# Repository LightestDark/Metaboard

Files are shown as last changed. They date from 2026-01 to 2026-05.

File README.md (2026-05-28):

# Metaboard
I made a small development board that uses a microcontroller to control an LED, letting it turn on, off, or blink based on the code running on it. It’s a simple platform for testing firmware, GPIO control, and basic hardware–software interaction.

# Production









# CASE




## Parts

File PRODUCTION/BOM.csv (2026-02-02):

JLCPCB BOM Tool - BOM Matching
BOM name?Metaboard-JLCPCB Assembly Order.xlsx |  |  |  | Download Time?2026-01-05 01:12:47 |  |  |  | * Our matching results are updated in real-time, but stock and prices may change. If it's been over 24 hours, please re-match before placing your order.
PCB Assembled Qty?5 |  |  |  | Est. Total Price?13.7934 (Pre-order parts require a quotation for final pricing.)
Your BOM |  |  |  | Matched Parts |  |  |  |  |  |  | Order Information
Designator | Comment | Footprint | JLCPCB Part # | Matches | Part # | Manufacturer | Footprint | Description | Category | Warning | JLCPCB Part # | Product link | Source | Lib Type | MOQ | Availability | My Parts(JLCPCB Parts) | My Parts(Global sourcing & consigned parts) | Rec. Order Qty | Unit Price ($) | Total Price ($)
C2,C3,C4,C5,C6,C7,C8,C9,C11,C12,C17 | 0.1uF | Capacitor_SMD:C_0402_1005Metric |  | Select by Customer | CL05B104KO5NNNC | Samsung Electro-Mechanics | Capacitor_SMD:C_0402_1005Metric | 100nF 16V X7R �10% 0402 Multilayer Ceramic Capacitors MLCC - SMD/SMT ROHS | Multilayer Ceramic Capacitors MLCC - SMD/SMT |  | C1525 | https://jlcpcb.com/partdetail/1877-CL05B104KO5NNNC/C1525 | In-stock | Basic | 1 | 40598460 | 0 | 0 | 65 | 0.0012 | 0.078
D1 | SK6812MINI | Flash:MX_SK6812MINI-E |  | Select by Customer | SK6812MINI-E | OPSCO Optoelectronics | Flash:MX_SK6812MINI-E | -40?~+85? 0.6mA 1.78mm 120� 1kHz 2.8mm 2000V 3.2mm 3.7V~5.5V 800Kbit/s G:815mcd~1275mcd R:620nm~625nm Semi-transparent lens SMD RGB LEDs(Built-in IC) ROHS | RGB LEDs(Built-in IC) |  | C5149201 | https://jlcpcb.com/partdetail/OPSCOOptoelectronics-SK6812MINIE/C5149201 | In-stock | Extended | 1 | 105235 | 0 | 0 | 7 | 0.0845 | 0.5915
R3,R4 | 27 | Resistor_SMD:R_0402_1005Metric |  | Select by Customer | 0402WGF270JTCE | UNI-ROYAL(Uniroyal Elec) | Resistor_SMD:R_0402_1005Metric | -55?~+155? 27? 50V 62.5mW Thick Film Resistor �1% �100ppm/? 0402 Chip Resistor - Surface Mount ROHS | Chip Resistor - Surface Mount |  | C25100 | https://jlcpcb.com/partdetail/25843-0402WGF270JTCE/C25100 | In-stock | Extended | 1 | 408109 | 0 | 0 | 22 | 0.0006 | 0.0132
Y1 | 12 MHz | Crystal:Crystal_SMD_3225-4Pin_3.2x2.5mm |  | Select by Customer | X322512MSB4SI | YXC Crystal Oscillators | Crystal:Crystal_SMD_3225-4Pin_3.2x2.5mm | -40?~+85? 12MHz 20pF Crystal Oscillator �10ppm �20ppm SMD3225-4P Crystals ROHS | Crystals | 1.The comment (X322512MSB4SI) of this part does not match the one (12 MHz) provided in your BOM. Please confirm; | C9002 | https://jlcpcb.com/partdetail/YXC_CrystalOscillators-X322512MSB4SI/C9002 | In-stock | Basic | 1 | 528140 | 0 | 0 | 9 | 0.0666 | 0.5994
C13,C14 | 10uF | Capacitor_SMD:C_0603_1608Metric |  | Select by Customer | CL10A106KP8NNNC | Samsung Electro-Mechanics | Capacitor_SMD:C_0603_1608Metric | 10V 10uF X5R �10% 0603 Multilayer Ceramic Capacitors MLCC - SMD/SMT ROHS | Multilayer Ceramic Capacitors MLCC - SMD/SMT | 1.The comment (CL10A106KP8NNNC) of this part does not match the one (10uF) provided in your BOM. Please confirm; | C19702 | https://jlcpcb.com/partdetail/20411-CL10A106KP8NNNC/C19702 | In-stock | Basic | 1 | 16279548 | 0 | 0 | 20 | 0.0057 | 0.114
U3 | W25Q16JVZPIQ TR | Flash:Winbond_USON-8-1EP_3x2mm_P0.5mm_EP0.2x1.6mm |  | Select by Customer | W25Q16JVUXIQ | Winbond Elec | Flash:Winbond_USON-8-1EP_3x2mm_P0.5mm_EP0.2x1.6mm | -40?~+85? 100,000 Cycles 10uA 133MHz 16Mbit 2.7V~3.6V 20 Years 3ms SPI USON-8-EP(2x3) NOR FLASH ROHS | NOR FLASH | 1.The comment (W25Q16JVUXIQ) of this part does not match the one (W25Q16JVZPIQ TR) provided in your BOM. Please confirm; | C2843335 | https://jlcpcb.com/partdetail/WinbondElec-W25Q16JVUXIQ/C2843335 | In-stock | Extended | 1 | 31866 | 0 | 0 | 5 | 0.6638 | 3.319
R1,R2 | 5.1k | Resistor_SMD:R_0402_1005Metric |  | Select by Customer | 0402WGF5101TCE | UNI-ROYAL(Uniroyal Elec) | Resistor_SMD:R_0402_1005Metric | -55?~+155? 5.1k? 50V 62.5mW Thick Film Resistor �1% �100ppm/? 0402 Chip Resistor - Surface Mount ROHS | Chip Resistor - Surface Mount |  | C25905 | https://jlcpcb.com/partdetail/26648-0402WGF5101TCE/C25905 | In-stock | Basic | 1 | 3708662 | 0 | 0 | 20 | 0.0006 | 0.012
U1 | RP2040 | Package_DFN_QFN:QFN-56-1EP_7x7mm_P0.4mm_EP3.2x3.2mm |  | Select by Customer | RP2040 | Raspberry Pi | Package_DFN_QFN:QFN-56-1EP_7x7mm_P0.4mm_EP3.2x3.2mm | 12bit 133MHz 30 LQFN-56(7x7) Microcontrollers (MCU/MPU/SOC) ROHS | Microcontrollers (MCU/MPU/SOC) |  | C2040 | https://jlcpcb.com/partdetail/RaspberryPi-RP2040/C2040 | In-stock | Extended | 1 | 63439 | 0 | 0 | 5 | 0.9366 | 4.683
R5,R6 | 1K | Resistor_SMD:R_0402_1005Metric |  | Select by Customer | 0402WGF1001TCE | UNI-ROYAL(Uniroyal Elec) | Resistor_SMD:R_0402_1005Metric | -55?~+155? 1k? 50V 62.5mW Thick Film Resistor �1% �100ppm/? 0402 Chip Resistor - Surface Mount ROHS | Chip Resistor - Surface Mount |  | C11702 | https://jlcpcb.com/partdetail/12256-0402WGF1001TCE/C11702 | In-stock | Basic | 1 | 13880356 | 0 | 0 | 20 | 0.0006 | 0.012
SW1 | SW_Push | Button_Switch_SMD:SW_Push_SPST_NO_Alps_SKRK |  | Select by Customer | TS-1088-AR02016 | XUNPU | Button_Switch_SMD:SW_Push_SPST_NO_Alps_SKRK | -30?~+80? 1.6N 100,000 Cycles 12V 2mm 3mm 4mm 50mA Black Round Button SMD(SMT) Tab SPST Surface Mount,Vertical Without Bracket SMD,4x3mm Tactile Switches ROHS | Tactile Switches |  | C720477 | https://jlcpcb.com/partdetail/XUNPU-TS_1088AR02016/C720477 | In-stock | Basic | 1 | 564276 | 0 | 0 | 9 | 0.0434 | 0.3906
C15,C16 | 33pF | Capacitor_SMD:C_0402_1005Metric |  | Select by Customer | 0402CG330J500NT | FH (Guangdong Fenghua Advanced Tech) | Capacitor_SMD:C_0402_1005Metric | 33pF 50V C0G �5% 0402 Multilayer Ceramic Capacitors MLCC - SMD/SMT ROHS | Multilayer Ceramic Capacitors MLCC - SMD/SMT | 1.The comment (0402CG330J500NT) of this part does not match the one (33pF) provided in your BOM. Please confirm; | C1562 | https://jlcpcb.com/partdetail/1914-0402CG330J500NT/C1562 | In-stock | Basic | 1 | 859839 | 0 | 0 | 20 | 0.0011 | 0.022
C1,C10 | 1uF | Capacitor_SMD:C_0402_1005Metric |  | Select by Customer | CL05A105KA5NQNC | Samsung Electro-Mechanics | Capacitor_SMD:C_0402_1005Metric | 1uF 25V X5R �10% 0402 Multilayer Ceramic Capacitors MLCC - SMD/SMT ROHS | Multilayer Ceramic Capacitors MLCC - SMD/SMT | 1.The comment (CL05A105KA5NQNC) of this part does not match the one (1uF) provided in your BOM. Please confirm; | C52923 | https://jlcpcb.com/partdetail/53938-CL05A105KA5NQNC/C52923 | In-stock | Basic | 1 | 10836716 | 0 | 0 | 20 | 0.003 | 0.06
R7 | 10K | Resistor_SMD:R_0402_1005Metric |  | Select by Customer | 0402WGF1002TCE | UNI-ROYAL(Uniroyal Elec) | Resistor_SMD:R_0402_1005Metric | -55?~+155? 10k? 50V 62.5mW Thick Film Resistor �1% �100ppm/? 0402 Chip Resistor - Surface Mount ROHS | Chip Resistor - Surface Mount |  | C25744 | https://jlcpcb.com/partdetail/26487-0402WGF1002TCE/C25744 | In-stock | Basic | 1 | 14280080 | 0 | 0 | 20 | 0.0006 | 0.012
U4 | MCP1700x-330xxTT | Package_TO_SOT_SMD:SOT-23 |  | Select by Customer | MCP1700T-3302E/TT | Microchip Tech | Package_TO_SOT_SMD:SOT-23 | -40?~+125?@(Tj) 1 1.6uA 178mV@(250mA) 250mA 3.3V 44dB@(100Hz) 6V Fixed Over Temperature Protection Positive SOT-23 Voltage Regulators - Linear, Low Drop Out (LDO) Regulators ROHS | Voltage Regulators - Linear, Low Drop Out (LDO) Regulators |  | C39051 | https://jlcpcb.com/partdetail/MicrochipTech-MCP1700T_3302ETT/C39051 | In-stock | Extended | 1 | 32386 | 0 | 0 | 5 | 0.3494 | 1.747
J2,J3 | Conn_01x20 | Connector_PinHeader_2.54mm:PinHeader_1x20_P2.54mm_Vertical |  | Select by Customer | 2.54-1*20P?? | BOOMELE(Boom Precision Elec) | Connector_PinHeader_2.54mm:PinHeader_1x20_P2.54mm_Vertical | -40?~+105? 1 1x20P 2.54mm 20P 3A Black Brass Pin Header Through Hole Plugin,P=2.54mm Pin Headers ROHS | Pin Headers |  | C50981 | https://jlcpcb.com/partdetail/51993-2_54_1_20P/C50981 | In-stock | Extended | 1 | 33409 | 0 | 0 | 10 | 0.1047 | 1.047
J4 | Conn_01x03 | Connector_PinHeader_2.54mm:PinHeader_1x03_P2.54mm_Vertical |  | Select by Customer | 1.27-1*3P? | BOOMELE(Boom Precision Elec) | Connector_PinHeader_2.54mm:PinHeader_1x03_P2.54mm_Vertical | -55?~+105? 1 1.27mm 1.7mm 1x3P 2.5mm 3A 3P 3mm Black Brass Pin Header Through Hole Plugin,P=1.27mm Pin Headers ROHS | Pin Headers |  | C24980 | https://jlcpcb.com/partdetail/25717-1_27_1_3P/C24980 | In-stock | Extended | 1 | 3038 | 0 | 0 | 8 | 0.0284 | 0.2272
J1 | USB_C_Receptacle_USB2.0_14P | Connector_USB:USB_C_Receptacle_HRO_TYPE-C-31-M-12 |  | Select by Customer | TYPE-C-31-M-12 | Korean Hroparts Elec | Connector_USB:USB_C_Receptacle_HRO_TYPE-C-31-M-12 | -30?~+80? 1 10,000 cycles 16P 20V 5A 7.35mm Female Surface Mount, Right Angle Type-C SMD USB Connectors ROHS | USB Connectors |  | C165948 | https://jlcpcb.com/partdetail/Korean_HropartsElec-TYPE_C_31_M12/C165948 | In-stock | Extended | 1 | 143077 | 0 | 0 | 5 | 0.1731 | 0.8655
U5 | OLED 0.93 | 0LED 0.93 INCH |  | Select by Customer | OLED-0.93 | Samsung Electro-Mechanics | OLED 0.93 | N/A | OLED SCREEN |  | C34693 | www.aliexpress.com/item/1005008660196594.html | In-stock | Extended | 1 |  |  |  |  |  | 6.23
3D PRINTING FEES |  |  |  |  |  |  |  |  |  |  |  |  |  |  |  |  |  |  |  |  | 5
JCLPCB ASSEMBLY FEE ( INCLUDES COMPONENT COSTS) |  |  |  |  |  |  |  |  |  |  |  |  |  |  |  |  |  |  |  |  | 82.00
 |  |  |  |  |  |  |  |  |  |  |  |  |  |  |  |  |  |  |  | TOTAL: | $87.00

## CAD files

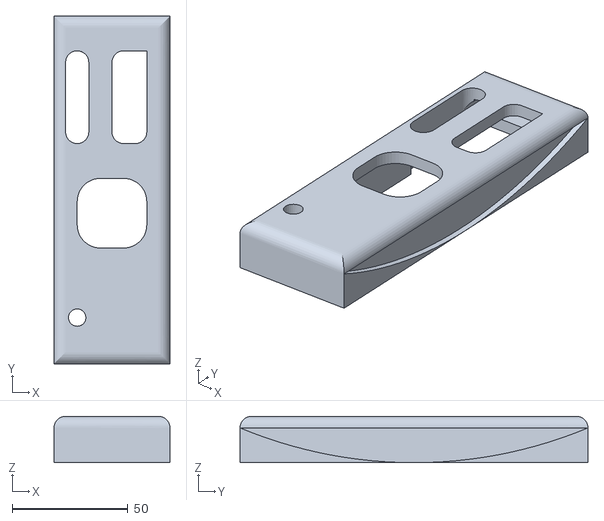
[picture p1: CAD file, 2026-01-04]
CAD/DEV BOARD CAD NEW.stl
50.0 x 150.0 x 20.0

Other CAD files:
CAD/DEV BOARD CAD.stl

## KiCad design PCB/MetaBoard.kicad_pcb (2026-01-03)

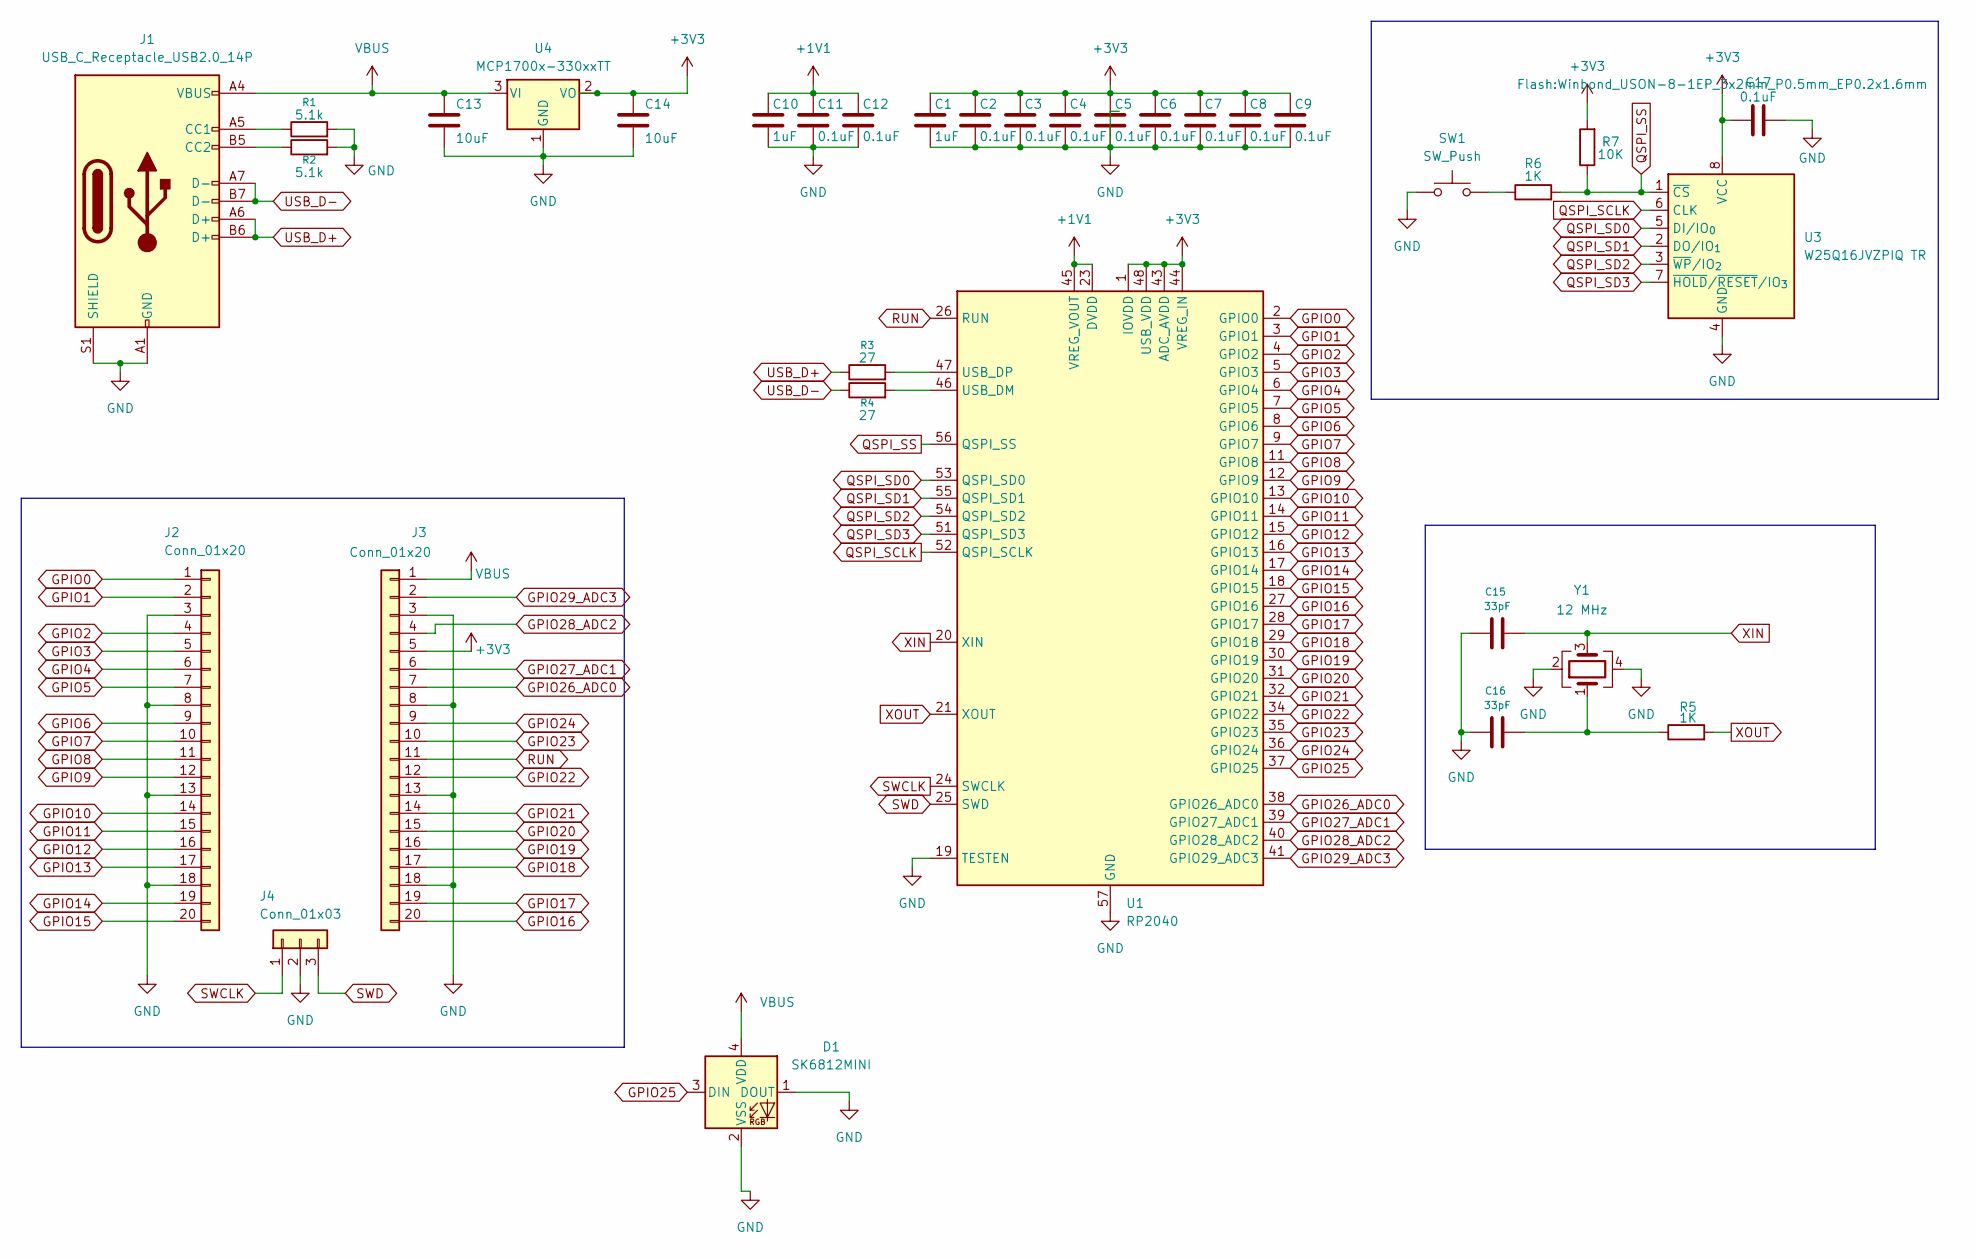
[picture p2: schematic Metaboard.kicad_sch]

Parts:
C1, C10: 1uF; C_0402_1005Metric
C2, C3, C4, C5, C6, C7, C8, C9, C11, C12, C17: 0.1uF; C_0402_1005Metric
C13, C14: 10uF; C_0603_1608Metric
C15, C16: 33pF; C_0402_1005Metric
D1: SK6812MINI; MX_SK6812MINI-E
J1: USB_C_Receptacle_USB2.0_14P; USB_C_Receptacle_HRO_TYPE-C-31-M-12
J2, J3: Conn_01x20; PinHeader_1x20_P2.54mm_Vertical
J4: Conn_01x03; PinHeader_1x03_P2.54mm_Vertical
R1, R2: 5.1k; R_0402_1005Metric
R3, R4: 27; R_0402_1005Metric
R5, R6: 1K; R_0402_1005Metric
R7: 10K; R_0402_1005Metric
SW1: SW_Push; SW_Push_SPST_NO_Alps_SKRK
U1: RP2040; QFN-56-1EP_7x7mm_P0.4mm_EP3.2x3.2mm
U3: W25Q16JVZPIQ TR; Winbond_USON-8-1EP_3x2mm_P0.5mm_EP0.2x1.6mm
U4: MCP1700x-330xxTT; SOT-23
Y1: 12 MHz; Crystal_SMD_3225-4Pin_3.2x2.5mm

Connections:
+1V1: C10.1, C11.1, C12.1, U1.23 (DVDD), U1.45 (VREG_VOUT), U1.50 (DVDD)
+3V3: C1.1, C2.1, C3.1, C4.1, C5.1, C6.1, C7.1, C8.1, C9.1, C14.1, C17.1, J3.5, R7.2, U1.1 (IOVDD), U1.10 (IOVDD), U1.22 (IOVDD), U1.33 (IOVDD), U1.42 (IOVDD), U1.43 (ADC_AVDD), U1.44 (VREG_IN), U1.48 (USB_VDD), U1.49 (IOVDD), U3.8 (VCC), U4.2 (VO)
GND: C1.2, C2.2, C3.2, C4.2, C5.2, C6.2, C7.2, C8.2, C9.2, C10.2, C11.2, C12.2, C13.2, C14.2, C15.1, C16.1, C17.2, D1.1 (DOUT), D1.2 (VSS), J1.A1 (GND), J1.A12 (GND), J1.B1 (GND), J1.B12 (GND), J1.S1 (SHIELD), J2.3, J2.8, J2.13, J2.18, J3.3, J3.8, J3.13, J3.18, J4.2, R1.2, R2.2, SW1.1, U1.19 (TESTEN), U1.57 (GND), U3.4 (GND), U4.1 (GND), Y1.2, Y1.4
GPIO0: J2.1, U1.2 (GPIO0)
GPIO1: J2.2, U1.3 (GPIO1)
GPIO2: J2.4, U1.4 (GPIO2)
GPIO3: J2.5, U1.5 (GPIO3)
GPIO4: J2.6, U1.6 (GPIO4)
GPIO5: J2.7, U1.7 (GPIO5)
GPIO6: J2.9, U1.8 (GPIO6)
GPIO7: J2.10, U1.9 (GPIO7)
GPIO8: J2.11, U1.11 (GPIO8)
GPIO9: J2.12, U1.12 (GPIO9)
GPIO10: J2.14, U1.13 (GPIO10)
GPIO11: J2.15, U1.14 (GPIO11)
GPIO12: J2.16, U1.15 (GPIO12)
GPIO13: J2.17, U1.16 (GPIO13)
GPIO14: J2.19, U1.17 (GPIO14)
GPIO15: J2.20, U1.18 (GPIO15)
GPIO16: J3.20, U1.27 (GPIO16)
GPIO17: J3.19, U1.28 (GPIO17)
GPIO18: J3.17, U1.29 (GPIO18)
GPIO19: J3.16, U1.30 (GPIO19)
GPIO20: J3.15, U1.31 (GPIO20)
GPIO21: J3.14, U1.32 (GPIO21)
GPIO22: J3.12, U1.34 (GPIO22)
GPIO23: J3.10, U1.35 (GPIO23)
GPIO24: J3.9, U1.36 (GPIO24)
GPIO25: D1.3 (DIN), U1.37 (GPIO25)
GPIO26_ADC0: J3.7, U1.38 (GPIO26_ADC0)
GPIO27_ADC1: J3.6, U1.39 (GPIO27_ADC1)
GPIO28_ADC2: J3.4, U1.40 (GPIO28_ADC2)
GPIO29_ADC3: J3.2, U1.41 (GPIO29_ADC3)
unnamed: C16.2, R5.1, Y1.1
unnamed: J1.A5 (CC1), R1.1
unnamed: J1.B5 (CC2), R2.1
unnamed: R6.1, SW1.2
unnamed: R4.2, U1.46 (USB_DM)
unnamed: R3.2, U1.47 (USB_DP)
QSPI_SCLK: U1.52 (QSPI_SCLK), U3.6 (CLK)
QSPI_SD0: U1.53 (QSPI_SD0), U3.5 (DI/IO_{0})
QSPI_SD1: U1.55 (QSPI_SD1), U3.2 (DO/IO_{1})
QSPI_SD2: U1.54 (QSPI_SD2), U3.3 (~WP/IO_{2})
QSPI_SD3: U1.51 (QSPI_SD3), U3.7 (~HOLD/~RESET/IO_{3})
QSPI_SS: R6.2, R7.1, U1.56 (QSPI_SS), U3.1 (~CS)
RUN: J3.11, U1.26 (RUN)
SWCLK: J4.1, U1.24 (SWCLK)
SWD: J4.3, U1.25 (SWD)
USB_D+: J1.A6 (D+), J1.B6 (D+), R3.1
USB_D-: J1.A7 (D-), J1.B7 (D-), R4.1
VBUS: C13.1, D1.4 (VDD), J1.A4 (VBUS), J1.A9 (VBUS), J1.B4 (VBUS), J1.B9 (VBUS), J3.1, U4.3 (VI)
XIN: C15.2, U1.20 (XIN), Y1.3
XOUT: R5.2, U1.21 (XOUT)

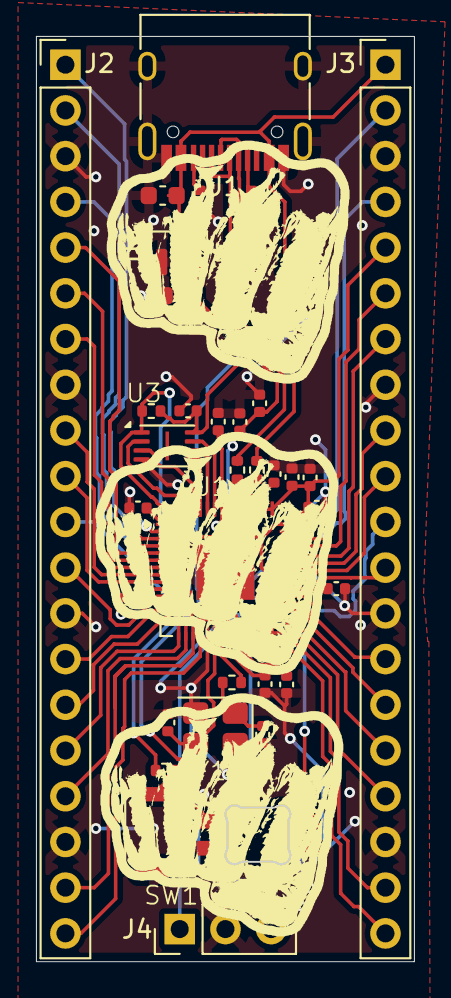
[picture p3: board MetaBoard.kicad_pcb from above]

Board: 2 copper layers, 21.0 x 51.4 mm, 34 parts (1 on the bottom side), 53 nets.

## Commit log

2026-01-03 Create BOM
2026-01-04 Update and rename BOM to BOM.csv
    [BOM.csv]
